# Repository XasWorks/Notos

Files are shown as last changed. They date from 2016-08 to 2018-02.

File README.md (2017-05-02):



# Notos



Public repository of the Notos robot project of the [Kolleg St. Thomas][kst] robotics group, competing in the 2016/2017 RoboCup Junior Line Secondary competition.

[kst]:http://www.kolleg-st-thomas.de

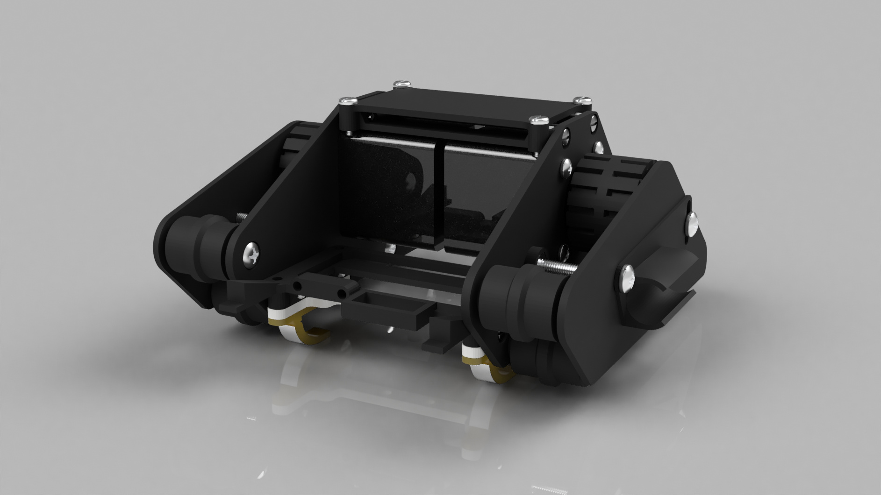
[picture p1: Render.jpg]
Autodesk Render
[](http://a360.co/2o4hNXv)

[a360render]:Render.jpg

----------

# Features
Notos was built mainly with DIY-capability in mind. All components can be printed out with a home 3D printer of normal size, and can be easily bought or soldered at home. The total costs lay beneath 100€

- AVR-Based MCU (ATMega32 and ATMega328P)
- NEMA 14 stepper motors for both precision and power
- Completely 3D printed chassis with sturdy screw-connections
	- This even includes the belts themselves! (Flexible material printing capabilities required though)
- Completely open-source code and design, for everyone to work with
- Simple "stacking" design for sensor mounts, PCBs and other attachments, allowing for a great deal of flexibility.

# History
Notos was started in the late summer of 2016, by DIY-enthusiast David Bailey.
After his mildly successfull run with his first robot [Zephyr][zephyrRepo], awarding him the 20th place in the german-open championship in the RoboCup Line Secondary contest in 2016, he applied his newfound knowledge to build something more suitable for the contest.
As a name, it was only fitting to continue Zephyr's legacy by choosing another greek god of the wind: **Notos**

[zephyrRepo]:https://www.github.com/XasWorks/Hexa-Bot

# Development
To overcome the problems that the old robot Zephyr had, a lot of the elements had to be replaced, and a complete redesign was necessary. This design process began in the late summer of 2016, maintaining many of the features that made Zephyr successfull, while swapping out the bad parts. The AVR-MCU and stepper motor drive system had been kept, while chassis and omniwheel-design were traded in for a much sturdier and compacter design, as well as more reliable, self-printed belts.

As of now the development still continues, as only over time differet features, flaws, and ideas come apparent.

---

# Prerequisites
- Using the OpenSCAD models here requires having the [XasCode Library][XasCode] next to this (the Notos) repository, as the Tagging.scad function is used.
	Later on the AVR libraries of that repository will also be used, so it is recommended to clone it completely!
- To properly work with the AVR Code, it is recommended to install the [AVR-Plugin for eclipse][avrplug] (for C and C++ eclipse versions)
	The current workspace is in EclipseWS. Eclipse should auto-detect the projects, if not, use the "import C++ project" function and import the project folders inside EclipseWS

[avrplug]:http://avr-eclipse.sourceforge.net/wiki/index.php/The_AVR_Eclipse_Plugin
[XasCode]:https://www.github.com/XasWorks/XasCode

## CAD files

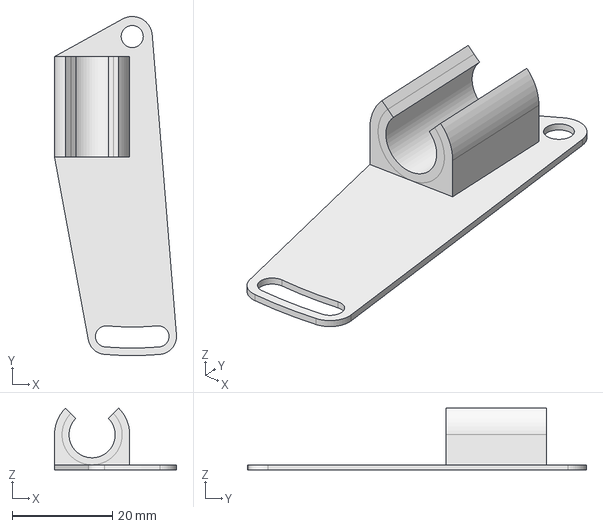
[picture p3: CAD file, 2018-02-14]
Models/BallSearch/BetterLaserSideMount.fcstd
24.3 x 67.6 x 12.3 mm

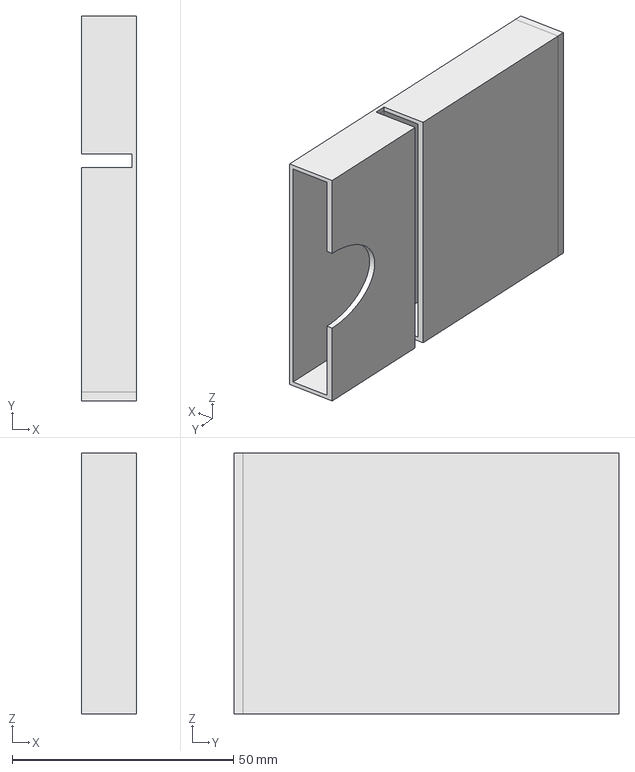
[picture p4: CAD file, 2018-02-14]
Models/Fancy/25_Card_Holder.fcstd
12.5 x 87.0 x 59.0 mm

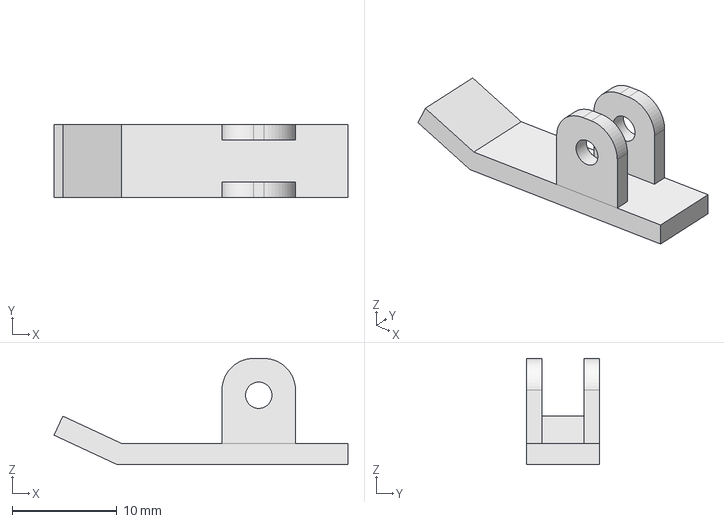
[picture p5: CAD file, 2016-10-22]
Models/Mechanics/Kufen.FCStd
28.0 x 7.00 x 10.1 mm

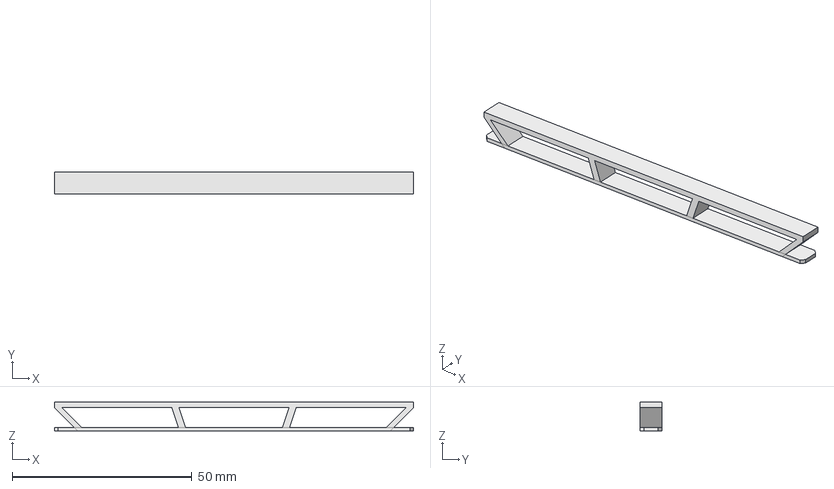
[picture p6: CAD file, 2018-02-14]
Models/Modules/Bumper/FrontBumpExtender.fcstd
100.0 x 6.00 x 8.00 mm

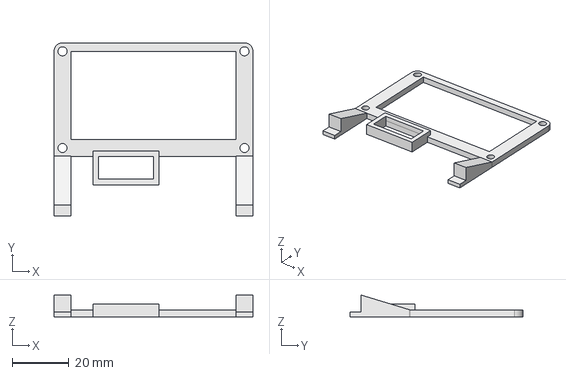
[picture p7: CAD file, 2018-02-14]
Models/Modules/Ground_Bumper_LZRGrey.fcstd
70.0 x 61.0 x 7.70 mm

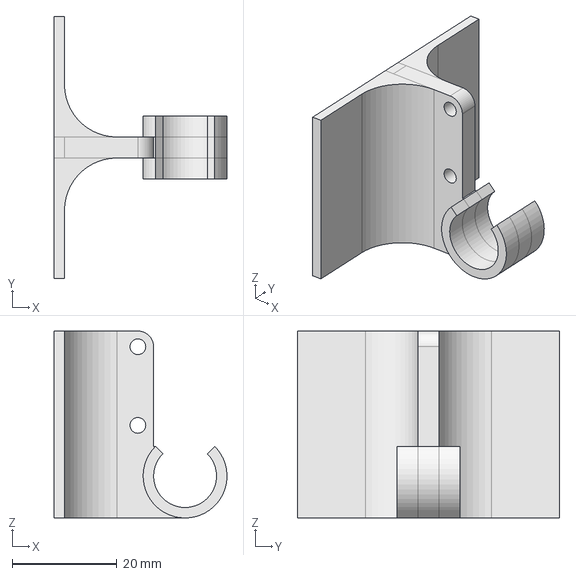
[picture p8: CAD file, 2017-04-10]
Models/Prototyping/LaserMounts/Laser_Greyscale_Mount.fcstd
33.0 x 50.0 x 35.7 mm

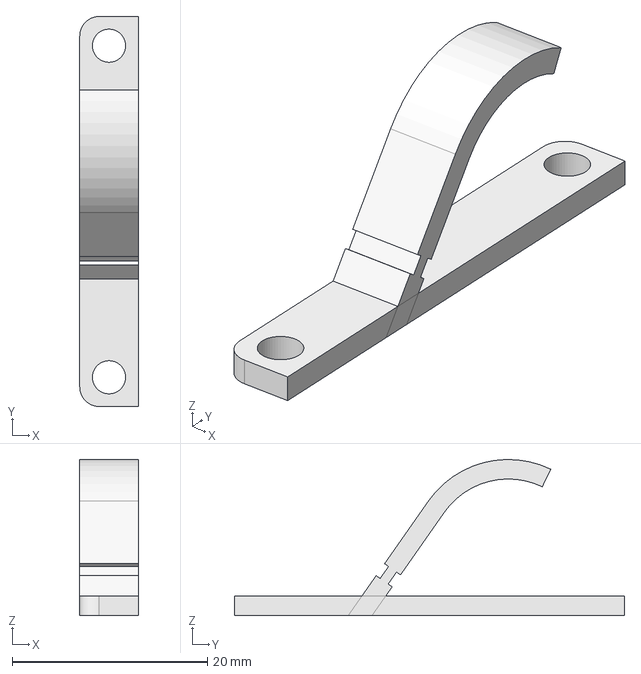
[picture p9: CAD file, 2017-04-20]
Models/BallSearch/Conductivity_Sensor.fcstd
6.00 x 40.0 x 16.0 mm

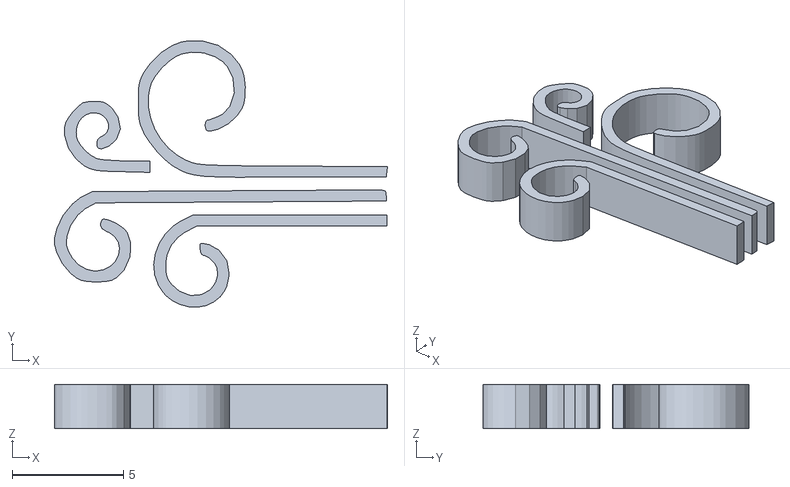
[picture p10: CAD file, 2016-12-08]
Models/Fancy/Logo.stl
15.0 x 12.0 x 2.00

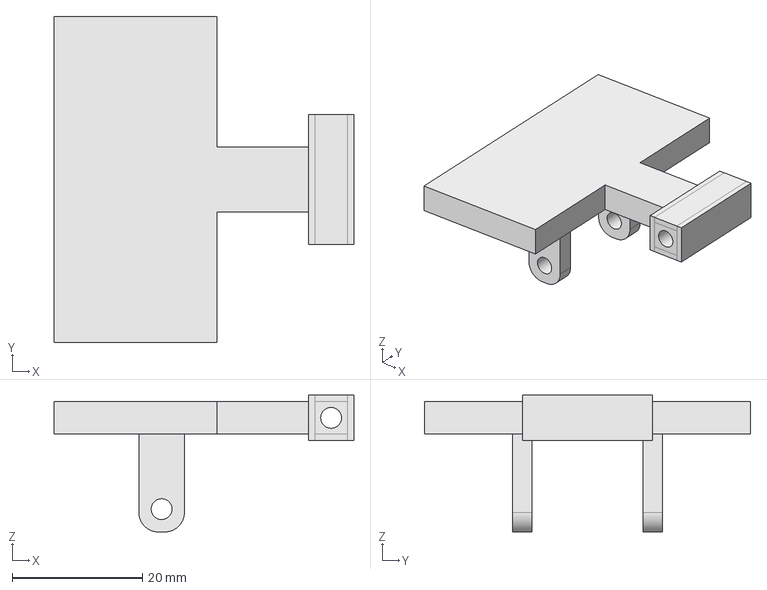
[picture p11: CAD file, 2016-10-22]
Models/Mechanics/LfMount.FCStd
46.0 x 50.0 x 21.0 mm

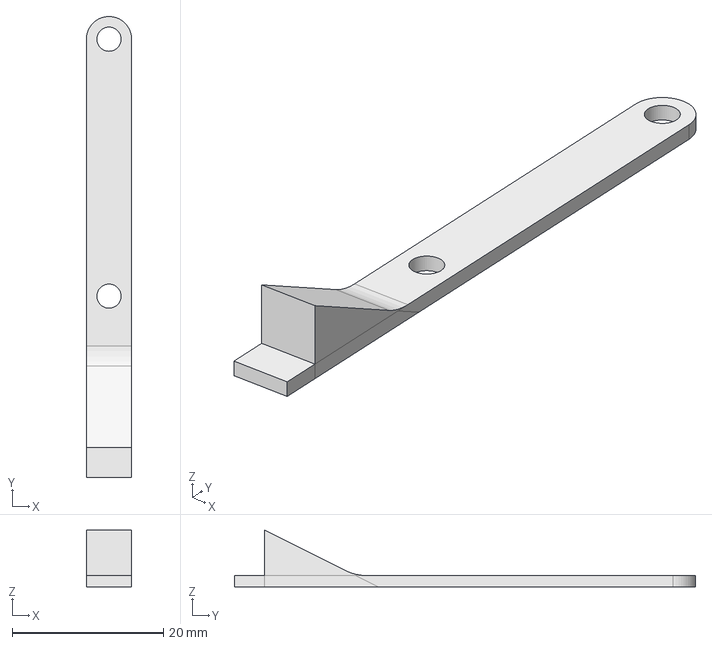
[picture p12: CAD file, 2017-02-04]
Models/Modules/Bumper/BumperSensor.fcstd
6.00 x 61.0 x 7.50 mm

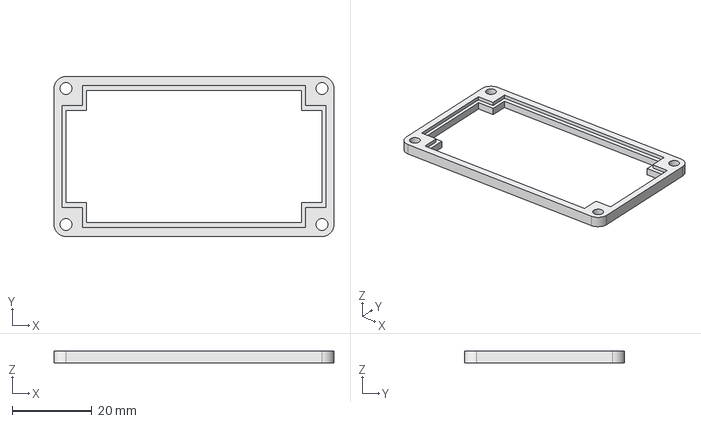
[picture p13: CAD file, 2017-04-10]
Models/Modules/LRP_Generic_Mount.fcstd
70.0 x 40.0 x 3.00 mm

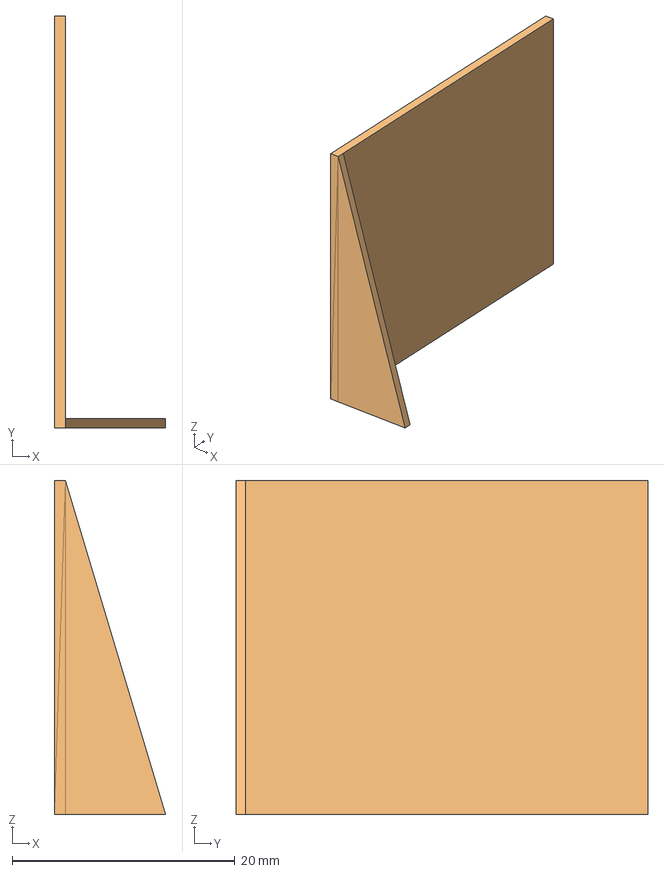
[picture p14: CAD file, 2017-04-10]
Models/Prototyping/LaserMounts/MountStabiliser.fcstd
10.0 x 37.0 x 30.0 mm

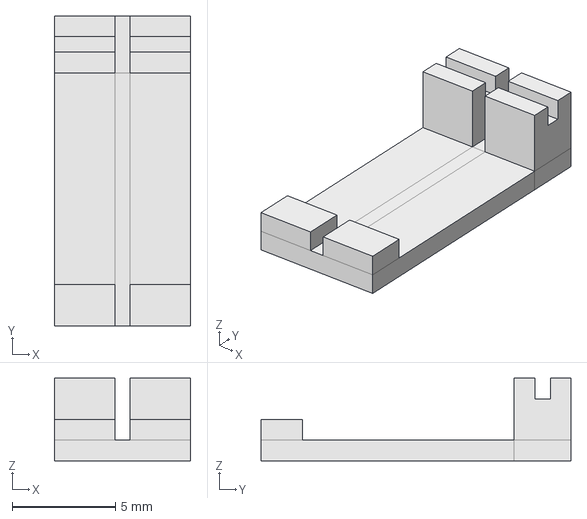
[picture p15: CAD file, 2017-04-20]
Models/BallSearch/BallBoopSensor.fcstd
6.60 x 15.0 x 4.00 mm

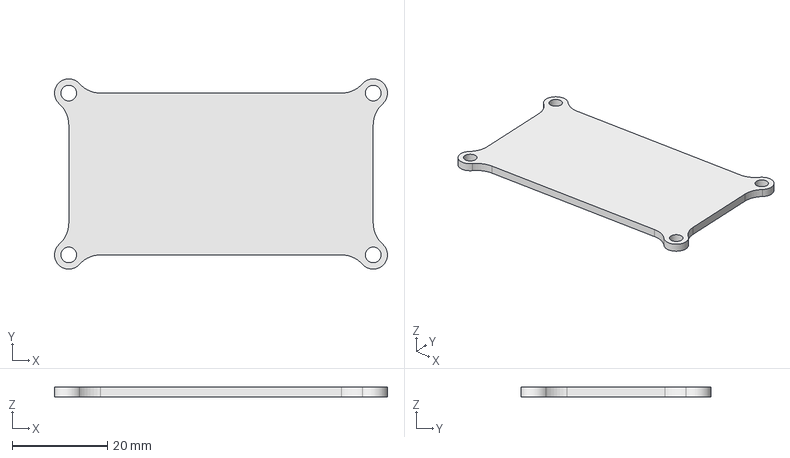
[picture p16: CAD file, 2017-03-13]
Models/Modules/BatteryMount.fcstd
70.0 x 40.0 x 2.00 mm

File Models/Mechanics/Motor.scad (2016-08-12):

include <../Values/Values.scad>

module motor_screws() {
	for (i = [0:90:360]) rotate([0, 0, i]) translate([motorMountscrewsDistance/2, motorMountscrewsDistance/2, 0])
	cylinder(d = 3 + playLooseFit * 2, h = motorBackplateHoleHeight + 2);
}

module motor_basic() {
	mSize = motorSizeWidth + playLooseFit * 2;
	translate([-mSize/2, -mSize/2, -10]) cube([mSize, mSize, 10]);
}

module motor_bphole() {
	cylinder(d = motorBackplateHoleDiameter + playLooseFit * 2, h = motorBackplateHoleHeight + 0.1);
}

module motor_axis() {
	difference() {
		cylinder(d = motorAxisFullDiam + playTightFit * 2, h = motorAxisFullLength + playLooseFit);

		translate([motorAxisFullDiam/2 - (motorAxisFullDiam - motorAxisIndentDiam) - playTightFit, -motorAxisFullDiam/2, motorAxisFullLength - motorAxisIndentLength])
			cube([motorAxisFullDiam, motorAxisFullDiam, motorAxisIndentLength + playLooseFit + 0.1]);
	}
}

module motor_cutouts(backplate_aligned = true) render(convexity = 5) {
	translate([0, 0, (backplate_aligned) ? -backplateThickness : 0]) {
		motor_axis();
		motor_screws();
		motor_basic();
		motor_bphole();
	}
}

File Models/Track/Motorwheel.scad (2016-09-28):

include <../Values/Values.scad>

use <../Mechanics/Motor.scad>
use <Track.scad>

module motorwheel_basic() {
	tag("positive") cylinder(r = motorWheelSize, h = trackWidth - 0.002);
}

module motorwheel_axisCutout() {
	tag("negative") translate([0, 0, -backplateThickness - plateTrackPlay]) motor_axis();
}

module motorwheel_trackCutout() {
	tag("negative") translate([0, 0, -0.001]) track(motorWheelSize + 0.001, clearance_offset = true);
}

module motorwheel() taggedDifference(["positive"],["negative"], "neural") {
	motorwheel_basic();
	motorwheel_axisCutout();
	motorwheel_trackCutout();
}

motorwheel();

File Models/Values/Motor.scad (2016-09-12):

// -- Werte der Schrittmotoren --

// Achsen-Werte
motorAxisIndentLength 	= 21;		// Länge der mit "Schnitt" versehenen Achsenstrecke.
motorAxisFullLength		= 21;		// Länge der gesamten Achse, gemessen vom Motor aus.
motorAxisIndentDiam 		= 4.5; 	// Diameter der "geschnittenen" Achsenstrecke
motorAxisFullDiam			= 5;		// Diameter der gesamten Achse.


// Generelle Motor-Werte
motorSizeWidth 				= 35;	// Breite des Motors
motorMountscrewsDistance 	= 26;	// Entfernung der Befestigungschrauben zueinander
motorBackplateHoleDiameter = 22;	// Größe der runden Fläche vorn am Motor, für die ein Loch gemacht werden muss.
motorBackplateHoleHeight 	= 2.5; // Höhe eben jener runden Fläche

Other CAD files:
Models/Modules/Bumper/FrontBumper.fcstd
Models/BallSearch/Laser Side Mount.fcstd
Models/Modules/MultiSensorMount.fcstd
Models/BallSearch/PhototransistorCover.fcstd
Models/Tools.scad
Models/Fancy/LogoPattern.scad
Models/Fancy/LogoStamp.scad
Models/Mechanics/ElectronicsSpacer.scad
Models/Mechanics/LFShield.scad
Models/Mechanics/Mechanics.scad
Models/Modules/AnalogLineFollorSensors.fcstd
Models/Modules/GroundDistanceSensor.fcstd
Models/Modules/LineFollowSensors.fcstd
Models/Modules/ModuleAdapter.scad
Models/Modules/ModuleMount.scad
Models/Modules/PartConnector.fcstd
Models/Modules/Prototype_Connector.fcstd
Models/Plating/Backplate.scad
Models/Plating/BasicPlating.scad
Models/Plating/Frontplate.scad
Models/Plating/PlateConnectors.scad
Models/Plating/PlatingSpacers.scad
Models/Prototyping/IdlerTest.scad
Models/Prototyping/TrackSetup.scad
Models/Track/Idler.scad
Models/Track/Track.scad
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

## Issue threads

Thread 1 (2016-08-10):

Einbau von einer Spiel-Variable (für 3D-Druck Kompatibilität)

Xasin, 2016-08-10:
Eine Spielraum-Variable sollte eingeführt werden, um die Notwendigkeit von Nacharbeiten zu vermindern.

Dies sollte in folgenden Dateien getan werden:

- [x] Mechanics/Mechanics.scad
- [x] Mechanics/Motor.scad
- [x] Track/Idler.scad

Closed 2016-08-10.

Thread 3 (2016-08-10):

Roboter-Logo

Xasin, 2016-08-10:
Design des Logos für den Notos-Roboter!
Bevorzugt Weiß-Auf-Schwartz, und im Rahmen von etwa 3x3cm

Xasin, 2016-09-17:
@FDCoreV2 und @Nuk213
Ihr könnt das gerne demnächst mal machen.

Felix, du hattest da schon einige gute Ideen.

Xasin, 2016-09-21:
@FDCoreV2 ganz deins!
Sorry @Nuk213 :P

FDCoreV2, 2016-09-27:
Idee, der ich unbedingt nachgehen sollte: vereinfachte Wellenformen zur Darstellung von Wind -> Notos = Windgott

Xasin, 2016-09-27:
Klingt gut!
Du kannst ja auf Google oder sowas nach Ideen suchen, aber am besten wäre halt immer noch irgend was selbst gemachtes.
Oh, auch bemerken:
- Das ganze geht als 2D-CAD oder als /Schwarz-Weiß/-PNG.
    - Dabei wäre mir schon das CAD oder eine Vector-Grafik lieber.
- Um die Größe musst du dir keine Sorgen machen, das vergrößert man sowieso passend.
- Am besten keine zu feinen Details, sonst drucken die nicht wirklich gut.

(Listen gehen übrigens dank Markdown, ist super einfach :P )

Xasin, 2016-11-24:
Angebracht und fancy gemacht!

Closed 2016-11-24.

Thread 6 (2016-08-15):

Neustrukturierung der Platzierung von versch. Backplate-Modellen

Xasin, 2016-08-15:
Umstrukturierung des Codes sodass nicht jedes Modul seinen eigenen Codeteil hat, nur um etwas an verschiedenen, in einem Array gegebenen Stellen zu platzieren.

Dateien, bei denen das vorkommt, sind:
- [x] Modules/ModuleMount.scad
- [x] Plating/BasicPlating.scad
- [x] Plating/PlateConnectors.scad

Closed 2016-08-21.

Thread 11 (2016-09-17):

Umstrukturierung der Halterung der Schrauben

Xasin, 2016-09-17:
Dafür müssen hauptsächlich die Muttern der M4-Schrauben entfernt werden.
Die Idee ist, dass die Frontplate dann das gesamte System zusammenhält, ohne dabei Druck auf die Kugellager aus zu üben, wodurch das System ruhig laufen sollte.

Die grundsätzlichsten Änderungen wären damit vermutlich auf der Frontplate.

Closed 2016-09-17.

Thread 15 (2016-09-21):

Verfeinerung des Roboter-Schaltplanes auf ein anderes Platinendesign!

Xasin, 2016-09-21:
Das neue Design sollte so gestaltet sein dass klar wird dass das elektrische System des Roboters auf einer getrennten Platine platziert wird, während die Steuerelektronik auf dem Haupt-breadboard liegt.

Xasin, 2016-09-22:
Dieses Issue ist gefixt in Commit #10921781a90

Closed 2016-09-22.

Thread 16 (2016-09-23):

Druckbarkeit der Schrauben-Halterung verbessern!

Xasin, 2016-09-23:
Angesichts dessen dass das XT-CF20 nur relativ schwierig Overhangs gut druckt, müssen die Schraub-Verbindungen umgeändert werden, um zumindest einen leichten Anstieg zu haben.

Geändert werden müssen:
- [x] Die Idlerwheel-Schrauben
- [x] Das Alignment der Idlerwheel-Schrauben sollte auch richtig eingestellt werden!
- [x] Und die Verbindungsschrauben Front zu Backplate!

Closed 2016-09-24.

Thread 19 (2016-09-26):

Verallgemeinerung einzelner Komponenten

Xasin, 2016-09-26:
Einige OpenSCAD-Modelle sollten vereinfacht werden, um das zukünftige Arbeiten mit ihnen zu erleichtern.

Hauptsächlich geht es dabei um die Platten-Verbinder, die momentan noch direkt positioniert werden.
Nicht gut.

Closed 2016-09-26.

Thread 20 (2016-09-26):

Passgenauigkeit der Schrauben verbessern!

Xasin, 2016-09-26:
Da muss noch einiges getan werden.
Die Schrauben selbst müssen enger sitzen, d.h. der Schrauben-Shaft muss ordentlich fest gegriffen werden (Idler-Mount, Frontplate/Backplate Connector), und die Länge der Schraube muss noch mit einbezogen werden!

Xasin, 2016-09-26:
Wird jetzt erstmal getestet!

Xasin, 2016-09-27:
Tests verliefen verdammt gut, das ist also kein Problem mehr :+1:

Closed 2016-09-27.

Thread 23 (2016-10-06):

Elektronik löten

Xasin, 2016-10-06:
Ziemlich selbstverständlich. Ich werd das demnächst machen :D

Xasin, 2016-10-09:
Yay!
Erster Teil des Chips ist fertig - Strom und Motorik :3

Xasin, 2016-10-16:
Zweiter Teil nun auch vollendet und getestet!
War schon vor einigen Tagen - Da kam dann aber Urlaub D:

Closed 2016-10-16.

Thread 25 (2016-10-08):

RGB-Led auf eigene Anschlüsse umverlegen.

Xasin, 2016-10-08:
Ist zwar kein zu wichtiger Fix, aber ich würde auch nicht wirklich gern den Programmer die LED mit treiben lassen.

Xasin, 2016-10-16:
Höchstwahrscheinlich gefixt in #388e848
Auf jeden Fall besitzen die LEDs nun ihren eigenen Anschluss - davon hat der Roboter ja genug :ok_hand:

Closed 2016-10-16.

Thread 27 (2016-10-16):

Stabilisation der Spannungs-Referenz

Xasin, 2016-10-16:
Ein Wiederstand muss zwischen ARef und Vcc eingebaut werden, um den Strom zu glätten und  somit immerhin wenigstens die Mindestbeschaltung für eine stabile Vergleichsspannung zu erfüllen.
Ziemlich straightforward, und benötigt nur minimales umlöten.

- [x] Umlötung der Beschaltung
- [ ] Änderung des Batterie Voltage-Dividers

Xasin, 2016-10-22:
Ok, das wurde jetzt ein wenig anders beschaltet:
Anstelle eines Widerstandes habe ich einfach nur den Kondensator von Vcc getrennt. Dadurch können wir sowohl AVcc als Referenz verwenden, als auch die interne 2.56V Referenz!

Da man jederzeit "umstellen" kann, werde ich zudem den Voltage-Divider so an passen, dass er ~15V auf 2.56 runter bring.

Xasin, 2016-10-22:
*Seufz*
Naja, die interne Voltage-Reference scheint mir etwas kaputt zu sein - sie liefert 4.3V, was eigentlich nicht sein sollte.

Die momentane Beschaltung regelt das ganze über einen 22Ω Wiederstand mit Kondensator, der dann eine 5V Referenz liefert, die immerhin ein kleines bisschen stabil sein sollte.

Closed 2016-10-22.

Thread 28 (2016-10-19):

Stapeln der Hauptplatinen mit Metallspacern

FDCoreV2, 2016-10-19:

Xasin, 2016-10-19:
@FDCoreV2
Hey warum soll ich das mit @richterkst machen?

:disappointed:

FDCoreV2, 2016-10-19:
@Xasin
Wir brauchen jemanden der uns Spacer besorgt!
:laughing:

Xasin, 2016-11-14:
Hey @richterkst, wir bräuchten noch die richtige Größe an Spacern - aber dann sollten wir dieses Issue schließen können! :D

Closed 2017-04-28.

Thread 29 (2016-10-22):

Fixen des 3D-Drucker Extruders

Xasin, 2016-10-22:
Das hier ist quasi der wichtigste Schritt beim ganzen Roboter-Drucken etc.
Wenn mein Drucker nicht klappt, wird der Roboter auch nicht gedruckt werden können - ungünstig, aber wahr.

Hauptsächlich muss nur das neue Teil bestellt werden.

Xasin, 2016-10-24:
Whooooo!
Reply von den Stoutwind Guys, die Schraube hat tatsächlich einen Fehler, die Charge wird überprüft, und wir kriegen bald hoffentlich ne funktionsfähige Halsschraube :3

Xasin, 2016-11-01:
### Update!
Neues Drucker-Teil wird bald geliefert! Mit etwas Glück ist es eine Halsschraube mit All-Metal Ende, welches sich für das CF20 eignet!
Wenn nicht, muss der Roboter eben aus normalem PLA gedruckt werden. Mal hoffen, dass @richterkst da nicht zu traurig drüber ist :disappointed:

Xasin, 2016-11-05:
## We did it, guys!
Der Drucker kann endlich wieder komplett arbeiten. Notos ahead!

Closed 2016-11-05.

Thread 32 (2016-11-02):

Verbesserung der Voltage-Detection

FDCoreV2, 2016-11-02:

Xasin, 2016-11-02:
Alles klar!
Kann ich demnächst machen ^^

Wird vielleicht ein wenig end, da ich demnächst relativ viel machen muss, aber das wird das nächst auf meinem Schirm sein :vulcan_salute:

Xasin, 2016-11-04:
Whoop whoop!
@FDCoreV2, auf XasWorks/XasCode ist eine Prototyp-Klasse für Batterie-Messung :D

Damit wird das hier bald fertig sein :3

Xasin, 2016-11-05:
Erledigt in #c07f49572ba1a76f0e9f072e1f5696f55cd51fba

Closed 2016-11-05.

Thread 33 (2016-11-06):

Druck brandneuer Idler-Wheels für bessere Kettenhalterung

Xasin, 2016-11-06:
Der neue Idler-Code ist schon da, er muss nur noch umgesetzt werden.
Mal schauen ob das dann klappt.

Xasin, 2016-11-09:
Jush, das wurd auch erledigt.
Ahoy für den fast fertigen Roboter! :D

Closed 2016-11-09.

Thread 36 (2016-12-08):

Implementierung von LineFollow Code

Xasin, 2016-12-08:
@Nuk213 sollte hoffentlich bald den Code an fangen können, sodass wir dann einen Roboter haben der auf tatsächlich der Linie folgen kann.

Folgende Kriterien stelle ich an den Code:
- [x] Sauber strukturiert, mit Tabs und ordentlicher Benennung
- [x] Sollte in seiner eigenen Datei, mit separater Header-Datei, angelegt werden
- [x] Das Line-Following sollte durch eine einzige signifikante Funktion aufgerufen werden können.
- [x] Der Code sollte die Daten der LFSensor Klasse nutzen, um dynamisch z. B. Drehrichtung zu berechnen. (Also KEIN Switch Case für jeden möglichen Zustand bitte)
- [x] Bei Verlust der Linie (Sensor.status == Lost) sollte der Roboter anhalten und sich Richtung Linie drehen.

Bei jeglichen Fragen einfach mich an sprechen ^-^

Vorher noch daran denken, Moritz, deinen Branch mit Master zu synchronisieren!

Xasin, 2017-01-05:
@Nuk213
So langsam wird es mal Zeit, dass wir etwas Bewegung hier sehen. Der Roboter sollte eigentlich schon fahren können, fehlt nur der Code!

Xasin, 2017-01-12:
@Nuk213
Wegen deinen Computer-Problemem gebe ich dir noch etwa zwei Wochen damit du die Code fertig machen kannst, OK?
Danach übernehme ich, der sollte halt einfach Ende Januar fertig werden.

Xasin, 2017-01-29:
Alles klar, behoben in commit 45850df!

Closed 2017-01-29.

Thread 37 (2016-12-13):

LF-Sensoren einstellen

Xasin, 2016-12-13:
Schwer kann es nicht sein - denkt man sich. Aber diese LineFollowing Sensoren sind wirklich nervig ...

Xasin, 2016-12-14:
Ok then!
Sie sind nicht ganz perfekt ... Aber das liegt glaube ich auch eher an den Sensoren selbst als an irgend etwas anderem. Aber sie erkennen die Linie sauber und präzise genug für Tests :D

Closed 2016-12-14.

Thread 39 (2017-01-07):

Bessere Nutzung der Pins.h

Xasin, 2017-01-07:
Da wir bereits eine Pin-Definitions-Datei haben, wäre es vermutlich angebracht eben jene auch etwas mehr zu nutzen.
An sich ist das nur eine kleine Änderung - Mal sehen wann ich das nutze.

Xasin, 2017-02-04:
Yay!
Closed dank #43

Closed 2017-02-04.

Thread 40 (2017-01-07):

Erstellung einer Kritischen-Batterie-Funktion

Xasin, 2017-01-07:
Angesichts dessen dass wir mit einem explosiven LiPo arbeiten, wäre es vermutlich einigermaßen gut, eben jenen auch etwas zu schonen - oder zumindest dafür zu sorgen, dass uns dieser nicht durch Unterladung um die Ohren fliegt.

Dafür bräuchten wir noch eine Funktion, die alles, was man ab schalten kann, auch ab schaltet - Hauptsächlich die Motoren.
Das ganze könnte dann an das Battery-Objekt angebunden werden, damit dieses diese Notfall-Funktion bei bedarf automatisch aus löst.

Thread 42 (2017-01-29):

Erstellen des Intersection-Code

Xasin, 2017-01-29:
Relativ simpel - geht eigentlich nur darum, dass der Roboter in bestimmten Situationen (den Intersektionen) sich in eine Richtung dreht.

Insgesamt muss:
- [x] Der dafür zuständige Code geschrieben werden, und
- [x] Die äußeren Line-Sensoren angeschlossen werden.

Xasin, 2017-02-21:
Im letzten PR, #48, geschlossen!

Closed 2017-02-21.

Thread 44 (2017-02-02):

Neue (Analoge) Sensoren verwenden!

Xasin, 2017-02-02:
Anstelle der momentanen, nur sehr schlecht einstellbaren und dementsprechend unpraktischen digitalen Sensoren sollte Notos besser die analogen LF-Sensoren verwenden.
Zusätzlich gibt es dadurch nicht drei, sondern vier Sensoren! Yay :+1:

Hierfür muss/müssen:
- [x] Die neuen Sensoren angebracht werden
- [x] Eine Analog-Update-Funktion verwendet werden, welche zusätzlich die "SensorsUpdated" Variable ordentlich verwaltet.
- [x] Ein neuer LF-Sensor-Code für vier Sensoren geschrieben werden.

Closed 2017-02-13.

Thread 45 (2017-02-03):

Analog-Distanz-Sensor für Rampen-Detektion anbauen

Xasin, 2017-02-03:
Relativ simpel an sich, der Code muss einfach nur so modifiziert werden dass die Grenzen des analogen Distanz-Sensors die `isTilted` Funktion als `true` ansetzten.

Also muss:
- [x] Eine Halterung für den Sensor gedruckt werden, und
- [x] Die `isTilted` Funktion eingestellt werden.

Closed 2017-02-13.

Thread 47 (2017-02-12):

Slow-Ramp Geschwindigkeitsberechnung einbinden

Xasin, 2017-02-12:
Für den Roboter sollte demnächst wohl gern eine "slow ramp-up" Geschwindigkeitsberechnung eingebaut werden, welche für gerade Strecken volle, für Kurven jedoch niedrigere  Geschwindigkeiten an strebt.

Um zusätzlich das Fahrverhalten des Roboters zu verbessern sollte die Geschwindigkeit nicht sofort wieder hoch gesetzt werden, sondern nach einer Auslenkung graduell erhöht werden, sodass der Roboter z.B. in Bereichen mit mehreren Kurven, oder bei Gegenden in denen enge Radien erfordert sind, nicht dauernd die Linie verliert.

Xasin, 2017-02-21:
Lief nicht ganz nach Plan - Stellt sich heraus dass zusammen mit dem Intersection-Code eine insgesamt kleinere Geschwindigkeit, sowie eine direkt proportionale Rampe, dann doch etwas besser ist!

Closed 2017-02-21.

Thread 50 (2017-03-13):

Re-Kalibration bestimmter Werte

Xasin, 2017-03-13:
Nach Anbringung des PlastiDip müssten einige Dinge auf Korrektheit überprüft werden:
- [ ] Rotations-Korrekturfaktor
- [ ] Die Intersection-Code Vorwärts-Bewegung

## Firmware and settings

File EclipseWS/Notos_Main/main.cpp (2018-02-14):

/*
 * main.c
 *
 *  Created on: Oct 9, 2016
 *      Author: xasin
 */

#include "main.h"
#include "Localcode/States/USB.h"
#include "Localcode/States/LineFollow.h"
#include "Localcode/States/BallCapture.h"

using namespace Robot;
using Communication::Pattern;

void (*stateFunction)();

// Eine "ISR"-Funktion ist eine Funktion, welche zu bestimmten Zeitpunkten automatisch aufgerufen wird.
// In dieserm Fall handelt es sich um die "TIMER1 - CompareInterrupt A" ISR. D.h. der Timer, hier aufgerufen alle 0.2ms
ISR(TIMER1_COMPA_vect) {
	ISR1();
}

// Diese ISR wird aufgerufen, wenn der ADC mit einer Umwandlung fertig ist. An sich ist es nur eine Hardware-Sache, also muss es nicht direkt verstanden werden.
ISR(ADC_vect) {
	ISRADC();
}

ISR(TWI_vect) {
	TWI::updateTWI();
}

// Die main-Methode des Roboters. Hier steht alles /wirklich/ wichtige drinnen, nämlich der eigentliche Programmcode.
int main() {

	switch(init()) {
	case powerupButton:
	case noVoltage:
	case noButton:
		stateFunction = &State::USB::simpleDebug;
	break;

	case lowBattery:
		Led.setModes(0b101101011, 0, 0);
		while(true) {}
	break;

	case startButton:
		setMotors(true);
		stateFunction = &State::LineFollow::simpleLF;
		//stateFunction = &State::Ball::ballSearch;
	break;
	}

	// Dauerschleife mit Motor-Test-Programm.
	while(1) {
		_delay_ms(10);
		if(stateFunction != 0)
			stateFunction();
	}

	return 1;
}

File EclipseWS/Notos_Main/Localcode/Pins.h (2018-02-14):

/*
 * Pins.h
 *
 *  Created on: Dec 14, 2016
 *      Author: xasin
 */

#ifndef LOCALCODE_PINS_H_
#define LOCALCODE_PINS_H_

#define PIN_ALF_SENSORS		0
#define PINx_ELF_SENSORS	PIND
#define	PIN_ELF_SENSORS		0

#define PIN_BATTERY 	7

#define PORTx_BUTTON	PORTB
#define PINx_BUTTON 	PINB
#define PIN_BUTTON 		4

#define PORTx_RGB 	PORTC
#define PIN_RGB_R		3
#define PIN_RGB_G		4
#define PIN_RGB_B		2

#define PORTx_STEPPERS 	PORTB
#define DDRx_STEPPERS	DDRB
#define PIN_STEPPER0_S	0
#define PIN_STEPPER0_D	2
#define PIN_STEPPER1_S	1
#define PIN_STEPPER1_D	2
#define PIN_STEPPER_E	3

#define PORTx_DINPUTS	PORTD
#define PINx_DINPUTS	PIND

#define PIN_BUMPER 		2
#define PIN_CONDUCTOR	4
#define PIN_BALLBOOP	3


#define PINx_TILT_SENSOR 3
#define PINx_GREEN_SENSOR	2

#endif /* LOCALCODE_PINS_H_ */

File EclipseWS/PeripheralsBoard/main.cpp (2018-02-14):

/*
 * main.cpp
 *
 *  Created on: 30.03.2017
 *      Author: xasin
 */

#include "AVR/ADC/ADC_Lib.h"
#include "AVR/TIMER/Timer1.h"
#include "AVR/TIMER/Timer0.h"

#include "AVR/Communication/NEW_TWI/TWI.h"

#include "Localcode/BallLaser.h"
#include "Localcode/ServoControl.h"

#include <avr/interrupt.h>

#include <util/delay.h>

BallLaser ballLaser(0, 0, &PORTB);
ServoControl servos = ServoControl();

ISR(TWI_vect) {
	TWI::updateTWI();
}

uint8_t timer0_presc_A = 0;
ISR(TIMER0_COMPA_vect) {
	switch(timer0_presc_A++) {
	default: break;

	case 0:
	ballLaser.update();
	servos.update();
	break;

	case 1:
	if(ballLaser.nextLaserOff())
		ballLaser.update();
	break;

	case 4:
	timer0_presc_A = 0;
	break;
	}
}

ISR(ADC_vect) {
	ADC_Lib::update();
	ballLaser.ADCUpdate();
}

int main() {
	DDRB |= (1<< PB0 | 1<< PB1 | 1<< PB2);
	DDRD |= (0b11 << PD6);

	Timer0::set_mode(TIMER0_MODE_CTC);
	Timer0::set_OCR0A(250 -1);					// With 256 prescaler, exactly 250Hz
	Timer0::set_prescaler(TIMER0_PRESC_256);

	TWI::init();
	TWI::setAddr(0x10);

	ADC_Lib::init(ADC_PRSC_128, ADC_REF_AREF);

	sei();

	_delay_ms(2000);
	servos.targetMode = RETRACTED;

	while(1) {
	}
}

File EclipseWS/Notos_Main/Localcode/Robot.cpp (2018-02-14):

/*
 * Robot.cpp
 *
 *  Created on: 31.10.2016
 *      Author: xasin
 */

#include "Robot.h"

// Directe Hardware-Libs
#include "../AVR/TIMER/Timer1.h"					// TIMER Bibliotheken
#include "../AVR/Actuators/Steppers/X2Stepper.h"	// Schrittmotor-Bibliothek
#include "../AVR/ADC/ADC_Lib.h"						// ADC-Bibliothek

namespace Robot {

using namespace Sensor;

X2::Stepper motorA = X2::Stepper(&PORTx_STEPPERS, PIN_STEPPER0_S, PIN_STEPPER0_D, ISR1_FREQ / ISR_CAL_FREQ, -STEPS_P_MM, STEPS_P_DEGREE);
X2::Stepper motorB = X2::Stepper(&PORTx_STEPPERS, PIN_STEPPER1_S, PIN_STEPPER1_D, ISR1_FREQ / ISR_CAL_FREQ, -STEPS_P_MM, -STEPS_P_DEGREE);

X2::Movable Motor = X2::Movable(ISR_CAL_FREQ);

Communication::RGBStatus Led = Communication::RGBStatus(&PORTx_RGB, PIN_RGB_R, PIN_RGB_G, PIN_RGB_B);

LF::ASens2 LSensor = LF::ASens2(PIN_ALF_SENSORS, &PINx_ELF_SENSORS, PIN_ELF_SENSORS);

Voltage::Battery Battery = Voltage::Battery(PIN_BATTERY, 15.682, SAFE_VOLTAGE, 12.9);

Peripheral::LaserFinder Laser = Peripheral::LaserFinder();

uint16_t ISR1PrescA = 1;
uint16_t ISR1PrescB = 1;
volatile uint8_t sensorStatus;
void ISR1() {
	// Aufruf der Schrittmotoren, um sich zu updaten.
	motorA.update();
	motorB.update();

	// "Prescaler", d.h. dass die nachfolgenden Funktionen nicht immer, sondern in längeren Abständen aufgerufen werden.
	if(--ISR1PrescA == 0) {
		Battery.update();
		Led.update();
		ISR1PrescA = ISR1_FREQ/ ISR_LED_FREQ;
	}

	if(--ISR1PrescB == 0) {
		ISR1PrescB = ISR1_FREQ / ISR_CAL_FREQ /2;
		if(sensorStatus != 0) {
			Motor.update();
			sensorStatus = 0;
		}
		else {
			Tilting::initMeasurement();
			LSensor.update();
			sensorStatus = 1;
		}
	}
}
void ISRADC() {
	ADC_Lib::update();
	Battery.ADC_update();
	Tilting::analogUpdate();
	LSensor.ADCUpdate();
}

void waitForSensors() {
	while(sensorStatus != 1 || !LSensor.isUpdated()) {
		_delay_ms(1);
	}
	sensorStatus = 2;
}

void setMotors(bool state) {
	if(state)
		PORTx_STEPPERS &= ~(1<< PIN_STEPPER_E);
	else
		PORTx_STEPPERS |= (1<< PIN_STEPPER_E);
}


bool getBumper() {
	return (PINx_DINPUTS & (1<< PIN_BUMPER)) == 0;
}
bool getButton() {
	return (PINx_BUTTON & (1<< PIN_BUTTON)) == 0;
}
bool getGroundConductive() {
	return (PINx_DINPUTS & (1<< PIN_CONDUCTOR)) == 0;
}
bool getBallBoop() {
	return (PINx_DINPUTS & (1<< PIN_BALLBOOP)) == 0;
}


InitStatus init() {
	// Initialisierung der Hardware-Pins (ähnlich des "pinMode" des Arduino)

	PORTx_BUTTON |= (1<< PIN_BUTTON);
	PORTx_STEPPERS |= (1<< PIN_STEPPER_E);
	DDRx_STEPPERS |= (1<< PIN_STEPPER_E);

	PORTx_DINPUTS |= (1<< PIN_BUMPER | 1<< PIN_BALLBOOP | 1<< PIN_CONDUCTOR);

	// Initialisierung des ADC
	ADC_Lib::init(ADC_PRSC_128, ADC_REF_AREF);

	TWI::init();

	// Initialisierung des Timer1 auf CTC (Clear Timer on Compare)-Modus. D.h. ganz normaler Timer Modus.
	Timer1::enable_CTC(ISR1_FREQ);

	// Startup-Button erkennen
	if(getButton())
		return InitStatus::powerupButton;

	_delay_ms(100);


	if(Battery.getVoltage() > SAFE_VOLTAGE) {
		Led.setModes(0b100100100100, 0b010010010010, 0b001001001001);
		for(uint8_t i = 10; i != 0; i--) {
			_delay_ms(450);
			if(getButton()) {
				return InitStatus::startButton;
			}
		}

		return InitStatus::noButton;
	}
	else if(Battery.getVoltage() > 2)
		return InitStatus::lowBattery;
	else
		return InitStatus::noVoltage;
}

}

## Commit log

2016-08-08 Started working on a first basic prototype model.
    [TrackSetup.scad]
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2016-08-08 Values.scad konfiguration in separaten Values-Ordner gelegt, um mehr Dateien für Konstanten verwenden zu können.
    [Mechanic.scad, TrackSetup.scad, Values.scad]
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2016-08-09 Werte für die Kette in einer andere Datei verschoben.
    [Track.scad, Values.scad]
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2016-08-09 Screw.scad zu Mechanics.scad umbenannt; Ball-Bearing und Nut hinzugefügt.
    [Mechanics.scad]
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2016-08-10 Hinzufügen eines ersten "offiziellen" Modelles einer Idler-Wheel Hälfte.
    Diese Hälfte soll später für die Aufhängung der Ketten verwendet werden, um sie in Platz zu halten.
    [Backplate.scad, Idler.scad, Mechanic.scad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]
2016-08-10 playTightFit und playLooseFit eingeführt, und in die jeweiligen Modell-Dateien eingebaut.
    Dieser Commit closes #1
    [Mechanics.scad, Motor.scad, Values.scad]
2016-08-10 Sicherstellung dass das Kugellager auch immer in das Idler-Wheel reinpasst.
    [Idler.scad]
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2016-08-11 Prototypendatei auf die neuen Motor-Räder und Idler umgestellt.
    [Idler.scad, Track.scad, TrackSetup.scad]
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2016-08-11 Erstes Modell des Schlittens für die LF Sensoren
    Der Name sagt das meiste, aber es fehlen noch Anbringungen der Sensoren aufgrund fehlender Größen und Daten.
    [Kufen.FCStd, LfMount.FCStd]
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2016-08-13 Zahn-Abstand so angepasst dass er sauber auf die Idler- und Motorräder passt.
    [Idler.scad, Track.scad]
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2016-08-15 Fertigstellung der Backplate! (#5)
    * Modell für die Roboter-Backplate erstellt.
    * Langer Variablenname kleiner gemacht.
    * Neues Backplate-Modell in die Prototypen-Form hinzugefügt.
    * Zahn-Abstand so angepasst dass er sauber auf die Idler- und Motorräder passt.
    * Einfügung von Anbringungs-Stellen für zukünftige Module.
    * Umbenennung von BackplateTrackPlay zu plateTrackPlay.
    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
    [Backplate.scad, Idler.scad, Mechanic.scad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]
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2016-08-21 Version 1.0 des Prototypen-Modells! (#7)
    * Einfügung der Platten-Verbindungselemente.
    * Leichtes Code-Cleanup, closes #6
    * Modell für die Frontplate hinzugefügt.
    * Neue Frontplatte zum Modell hinzugefügt.
    * Hardgecodeten Schrauben-Durchmesser durch Variable ersetzt.
    * Prototypen-modell auf zwei Setups erweitert.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
    [Backplate.scad, Frontplate.scad, Idler.scad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]
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2016-09-17 Design umgeändert auf Nutless design. Closes #11 (Sollte es zumindest).
    Geändert wurden hauptsächlich:
    - Frontplate
    - Backplate
    - idlerwheel_screw
    Die Änderung in Motorwheel.scad ist ein bug, entstanden durch die Änderung von Track.scad
    [Backplate.scad, Frontplate.scad, Idler.scad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]
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2016-09-22 Beendung des Umänderns des Platinen-Designs. Das neue System beinhaltet nun: - Alle für den Roboter relevanten Bauteile (inclusive A4988 Treiber) - Erweiterte Dokumentation des Schaltkreises - Ein se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
    [MainBoard.sch, PSU.sch]
2016-09-24 Redesign der Idler_Screws für #16
    Das Redesign:
    - sorgt dafür, dass die Schrauben an der richtigen Position sitzen (Anfang des Schraub-Schaftes am Anfang der BP),
    - räumt ein wenig auf und
    - Fügt den Fix für den einfachereren Druck (config wert idlerScrewHeadSlope) hinzu.
    [Mechanic.scad, Mechanics.scad]
2016-09-24 Frontplate-Schrauben auf Idler-Schrauben gesetzt
    Dieser Commit ersetzt die alten "handgemachten" Schraubenmodelle für die Frontplate/Backplate Verbindung durch die Idler-Screw Modelle.
    Dadurch: closes #16
    [Frontplate.scad, PlateConnectors.scad]
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2016-09-26 Frontplate für #19 verändert.
    frontplate_screw_cuts und frontplate_spacers wurden aufgespalten, sodass nun das eigentliche "Einzelelement" verfügbar ist.
    Yay
    [Frontplate.scad]
2016-09-26 Plate connectors für #19 verändert.
    Jetzt sind auch die jeweiligen "Connectoren" verfügbar. Yay!
    [PlateConnectors.scad]
2016-09-26 Wertejustierungen für #20 Hauptsächlich sind die Werte der Größen für den Schrauben-Kopf und -Shaft verändert worden, um alles etwas besser zusammen zu halten.
    [Mechanic.scad, Mechanics.scad, Plating.scad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]
2016-09-26 Nutzung von Muttern für Stabilität (#20)
    Hiermit werden Muttern anstelle von gedruckten Anbringungen verwendet.
    Die Muttern müssen eingeklebt werden, sorgen danach aber für problemlosen Halt.
    [Backplate.scad, PlateConnectors.scad]
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2016-09-29 Hinzufügung eines lagerlosen Idlerwheel
    Es sollte sich in einem Stück drucken lassen, und auch ohne Bearings sehr reibungsarm laufen können!
    ---
    Zudem wurde auch noch smallWheelSize zu idlerwheelSize umbenannt, um alles etwas konsistenter zu halten!
    [Idler.scad, IdlerTest.scad, Track.scad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]
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2016-09-29 Option für ein "Sleek" Design
    Mit dieser Option werden die Schrauben innerhalb der Platte, und nicht mit separatem Block, angebracht, wodurch alles etwas sauberer wird.
    [ModuleAdapter.scad, Modules.scad]
2016-09-29 TrackSetup um Adapterplatten erweitert
    UNGLAUBLICH Sorry für den accidental merge mit master.
    *seufz*
    Mein Fehler.
    [TrackSetup.scad]
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2016-10-04 Namensgebung ein wenig angepasst, fixes #22
    [ModuleAdapter.scad, Modules.scad, TrackSetup.scad]
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2016-11-26 Hinzufügen eines LF-Sensor-Schirmes Müssen noch getestet werden, ob sie die präzision wirklich verbessern!
    Closes #34
    [LFShield.scad]
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2016-12-08 Anpassungen an das gedruckte Modell sowie neue StatusLED
    Folgende Änderungen wurden zusätzlich getan:
    - Änderung für simplere, bessere Idlerwheels
    - Kleine Änderung für besseren Halt
    [Frontplate.scad, Idler.scad, Track.scad]
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2016-12-08 Säuberung für PR #35
    - Entfernung von check_voltage, für #35
    - Hinzufügen von ISR_LED_FREQ, #35
    - Kleines unnötiges # entfernt
    [Frontplate.scad]
2016-12-08 David.wip (#35)
    * Dickere Wände für die Frontplate
    * Einbindung eines Battery-Guards
    * Anpassungen an das gedruckte Modell sowie neue StatusLED
    * Änderung für simplere, bessere Idlerwheels
    * Kleine Änderung für besseren Halt
    * Einfügung eines Prototypen-Modul-Verbinders
    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
    [ElectronicsSpacer.scad, Frontplate.scad, Idler.scad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]
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2017-01-27 Added object avoidance code!
    [LineFollow.cpp, LineFollow.h]
2017-02-01 Added a tilt/accelleration sensor. TODO: Replace with a short-range distance sensor to properly detect the falling-edge of a ramp
    [AccellSensor.cpp, LineFollow.cpp, Pins.h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]
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2017-02-03 Fix for #43, small fixes for #39
    [AccellSensor.cpp, Robot.cpp]
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2017-02-04 Neue Linien- und Boden-Sensoren ordentlich eingebunden
    Fixes #44 and fixes #45
    [LineFollow.cpp, LineFollow.h, Pins.h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]
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2017-03-09 Added capability to change object avoid direction.
    [Utility.cpp, Utility.h]
2017-03-09 Improvements to bump/ramp avoidance & buttonPause
    [Utility.cpp]
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2017-03-13 Implementation of a circle-based avoid code
    [Utility.cpp, Utility.h]
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2017-03-27 {New models for a LRP and the distance, bumper & laser sensor}
    [Ground_Bumper_LZRGrey.fcstd, LRP_Generic_Mount.fcstd]
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2017-04-04 Apparently, wasn't saved correcty!
    [PeripheralsModule.sch]
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2017-04-10 Laser & Peripherals Module! (#51)
    * DO. NOT. DELETE. CPROJECT
    * Added new prototyping model to mount a laser & greyscale.
    * Start of the peripherals module design!
    * Adjusted the mount for 12mm laser
    * Value adjustments
    * Added a side-mounted laser attachment
    * Smaller walls to allow the screw to still screw in >.>
    * {New models for a LRP and the distance, bumper & laser sensor}
    * Made the laser mount smaller
    * Arranged the PCB properly.
    * Apparently, wasn't saved correcty!
    * Addition of variable pull-down for A0
    * New AVR Workspace for the peripherals board!
    This includes a nice TWI-Compatible class to handle the laser :D
    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
    [BetterLaserSideMount.fcstd, Ground_Bumper_LZRGrey.fcstd, LRP_Generic_Mount.fcstd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]
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2017-04-20 Fixes for PR #52
    [BallLaser.cpp]
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2017-04-26 Started work on a improved rotation method.
    Using a bit of algebra, this should prevent any rotations > 180
    Thusly, speeding up the robot and reducing imprecisions.
    Also, looks a bit more impressive.
    [BallCapture.cpp]
2017-04-27 Fixed rotation, better drop detection & self-alignment
    [BallCapture.cpp]
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2017-05-02 Fixed the "Robot does not return" bug
    [BallCapture.cpp]
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
